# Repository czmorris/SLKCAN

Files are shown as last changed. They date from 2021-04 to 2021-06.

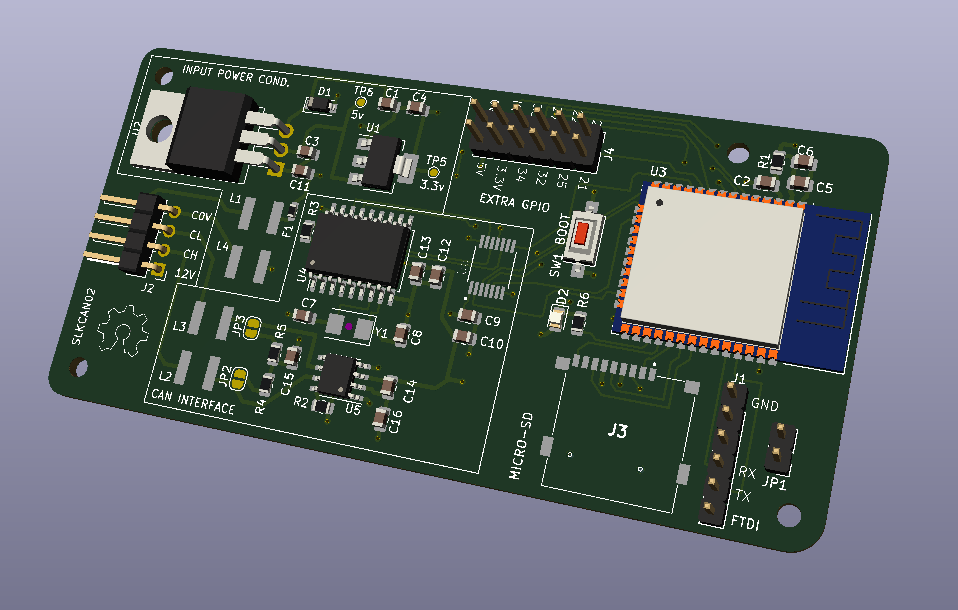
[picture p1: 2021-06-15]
SLKCAN/Renders/Front.PNG

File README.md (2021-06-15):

# SLKCAN
SLKCAN (Slick CAN) PCB. 

This board was created as project to connect to the CANBus on a City Slicker electric motorcycle (Though it may work with other canbus devices).

Goal:
- Programmable via the Arduino IDE (Uses an ESP32). This allows anyone who uses it to customize it to their own needs.
- Connect to the CANBus on the motorcycle. (Uses MCP2551 and MCP2515, Noise management was also required)
- Provide a means to get 3.3 and 5v power from the 12v supply on the bikes data port.
- Provide a means to get this information out via serial. Or to be reprogrammed via serial. Pin header provided.
- Provide a header with some additional GPIO.

note: I use an FTDI cable for programming and getting serial terminal information.
I have also tested with cheaper USB TTL modules with no issues. Other adapters may work as well.

At this time this device does not promise to be foolproof. Connect this to your bike at your own risk.

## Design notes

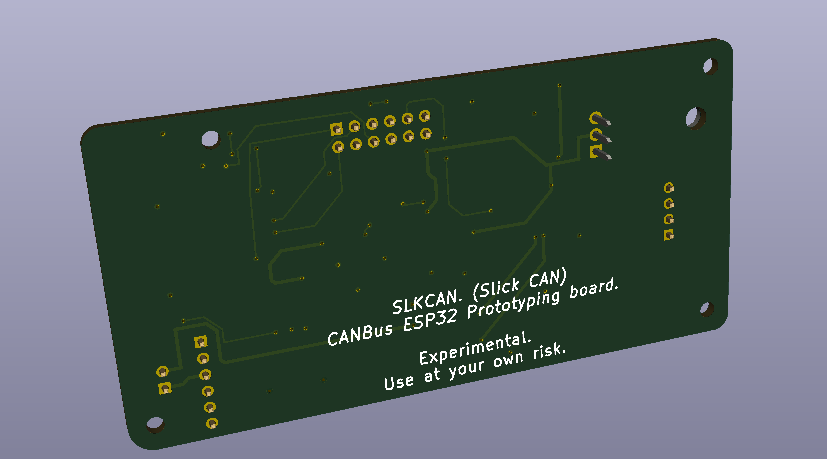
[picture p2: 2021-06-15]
SLKCAN/Renders/Back.PNG

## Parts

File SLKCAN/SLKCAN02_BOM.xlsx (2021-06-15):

Comment | Designator | Footprint | LCSC Part #（optional）
15uH Ind | L1, L2, L3, L4 | SWPA5020 | C55435 (https://lcsc.com/product-detail/Power-Inductors_Sunlord-SWPA5020S150MT_C55435.html/?href=jlc-SMT)
Fuse | F1 | 603 | C207010 (https://lcsc.com/product-detail/PTC-Resettable-Fuses_Littelfuse-0603L010YR_C207010.html/?href=jlc-SMT)
5vREG | U2 | TO-220 | C283283 (https://lcsc.com/product-detail/Dropout-Regulators-LDO_STMicroelectronics-LD1085V50_C283283.html/?href=jlc-SMT)
3.3REG | U1 | SOT-223 | C6186 (https://lcsc.com/product-detail/Low-Dropout-Regulators-LDO_AMS_AMS1117-3-3_AMS1117-3-3_C6186.html/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)
ESP | U3 | QFN-38 | C82899 (https://lcsc.com/product-detail/WIFI-Modules_Espressif-Systems-ESP32-WROOM-32_C82899.html/?href=jlc-SMT)
SD | J3 | 14.5x14.75X1.85mm | C111196 (https://lcsc.com/product-detail/Card-Sockets-Connectors_SOFNG-TF-15x15_C111196.html/?href=jlc-SMT)
LVL IC | U6 | TSSOP-14 | C44955 (https://lcsc.com/product-detail/Level-Translators-Shifters_Texas-Instruments-TXS0104EPWR_C44955.html)
MCP | U4 | SOIC-18 | C12368 (https://lcsc.com/product-detail/CAN_MICROCHIP_MCP2515-I-SO_MCP2515-I-SO_C12368.html/?href=jlc-SMT)
MCP | U5 | SOIC-8 | C49558 (https://lcsc.com/product-detail/MICROCHIP_MICROCHIP_MCP2551T-I-SN_MCP2551T-I-SN_C49558.html/?href=jlc-SMT)
XTAL | Y1 | SMD-5032 | C115962 (https://lcsc.com/product-detail/SMD-Crystal-Resonators_Yangxing-Tech-X50328MSB2GI_C115962.html/?href=jlc-SMT)
DIODE | D1 | SOD-123 | C727113 (https://lcsc.com/product-detail/Schottky-Barrier-Diodes-SBD_TWGMC-1N5817W_C727113.html/?href=jlc-SMT)
LED | D2 | LED_0805 | C84256 (https://lcsc.com/product-detail/Light-Emitting-Diodes-LED_Red-LED-SMDLED-80-180mcd_C84256.html/?href=jlc-SMT)
.1uF | C6, C9-13, C16 | 805 | C696367 (https://lcsc.com/product-detail/Multilayer-Ceramic-Capacitors-MLCC-SMD-SMT_KEMET-C0805C104K1RECAUTO_C696367.html/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)
10uF | C1, C3-5 | 805 | C15850 (https://lcsc.com/product-detail/Multilayer-Ceramic-Capacitors-MLCC-SMD-SMT_SAMSUNG_CL21A106KAYNNNE_10uF-106-10-25V_C15850.html/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)
1uF | C2 | 805 | C28323 (https://lcsc.com/product-detail/Multilayer-Ceramic-Capacitors-MLCC-SMD-SMT_SAMSUNG_CL21B105KBFNNNE_1uF-105-10-50V_C28323.html/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)
22pF | C7, C8 | 805 | C1804 (https://lcsc.com/product-detail/Multilayer-Ceramic-Capacitors-MLCC-SMD-SMT_SAMSUNG_CL21C220JBANNNC_22pF-220-5-50V_C1804.html/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)
150pF | C14, C15 | 805 | C1716 (https://lcsc.com/product-detail/Multilayer-Ceramic-Capacitors-MLCC-SMD-SMT_150pF-151-10-50V_C1716.html/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)
10K | R1-3 | 805 | C17414 (https://lcsc.com/product-detail/Chip-Resistor-Surface-Mount_Uniroyal-Elec-0805W8F1002T5E_C17414.html/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)
1K | R6 | 805 | C17513
60 | R4-5 | 805 | C72998 (https://lcsc.com/product-detail/Chip-Resistor-Surface-Mount_Uniroyal-Elec-0805W8F604JT5E_C72998.html/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)
BTN | SW1 | SW-SMD-3.6X6.1 | C118141 (https://lcsc.com/product-detail/Tactile-Switches_Korean-Hroparts-Elec-K2-1107ST-A4SW-06_C118141.html/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)

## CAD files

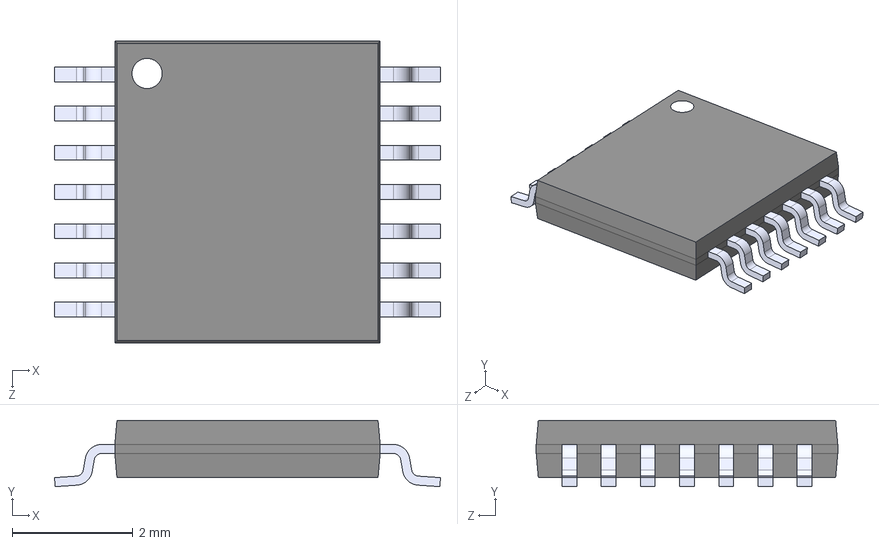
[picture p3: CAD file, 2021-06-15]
SLKCAN/downloads/74LVC125APW_118/74LVC125APW_118.step
6.40 x 1.10 x 5.00 mm

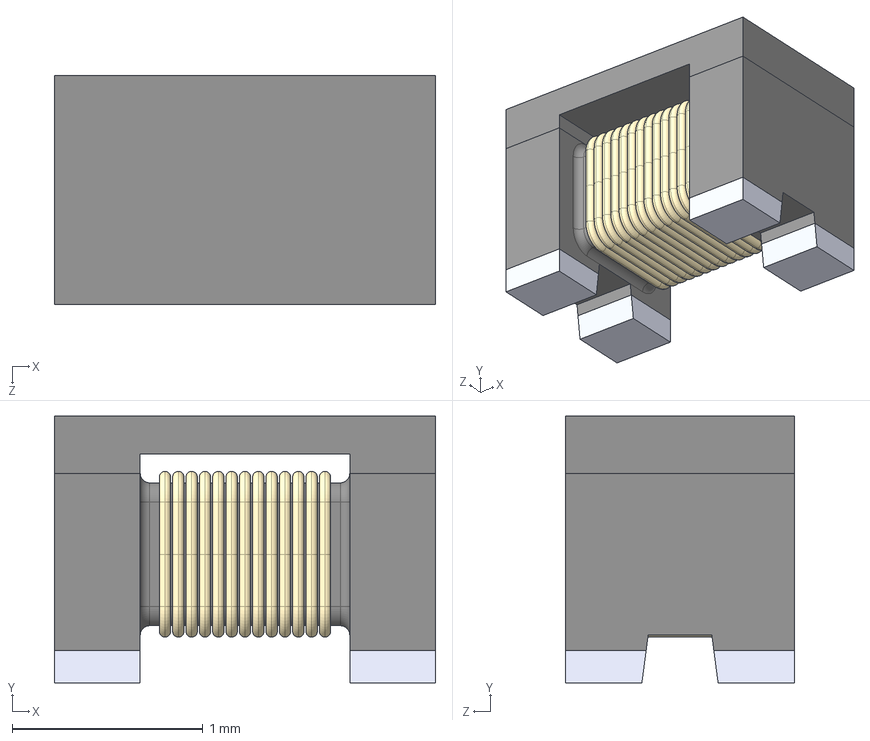
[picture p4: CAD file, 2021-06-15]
SLKCAN/downloads/DLW21SN121SQ2L/DLW21SN121SQ2L.step
2.00 x 1.40 x 1.20 mm

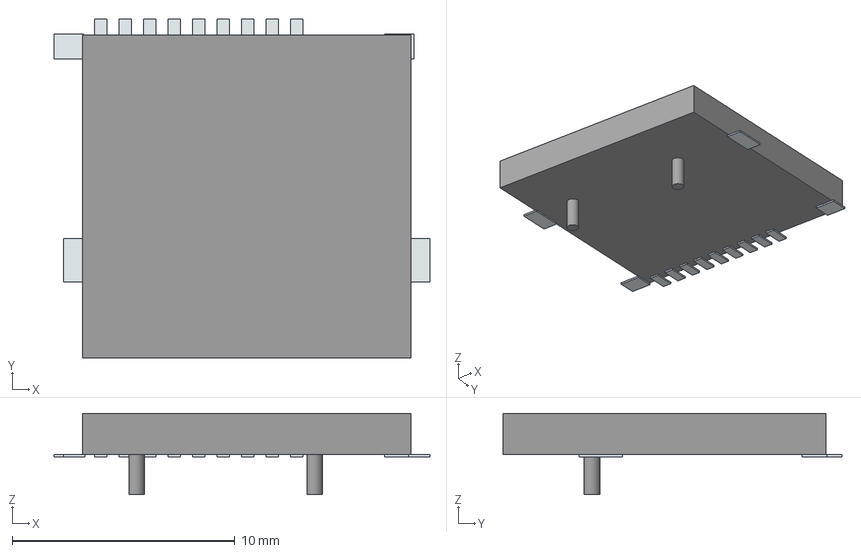
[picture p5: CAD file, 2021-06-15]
SLKCAN/downloads/LIB_TF-15X15/TF-15X15/3D/TF-15X15.stp
16.9 x 15.2 x 3.65 mm
Pins
Lugs x 2

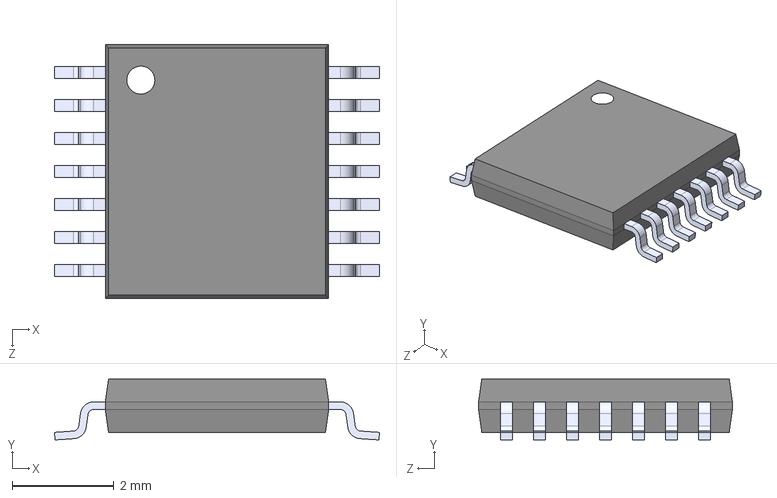
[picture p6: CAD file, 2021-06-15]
SLKCAN/downloads/LSF0204PWR/LSF0204PWR.step
6.40 x 1.20 x 5.00 mm

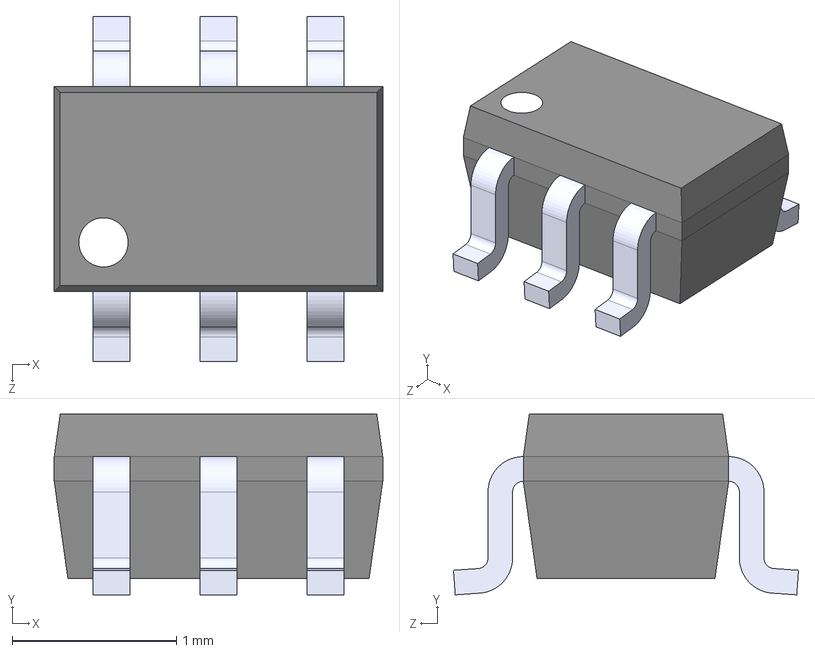
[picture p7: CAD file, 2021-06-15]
SLKCAN/downloads/SN74AVC1T45DCKR/SN74AVC1T45DCKR.step
2.00 x 1.10 x 2.10 mm

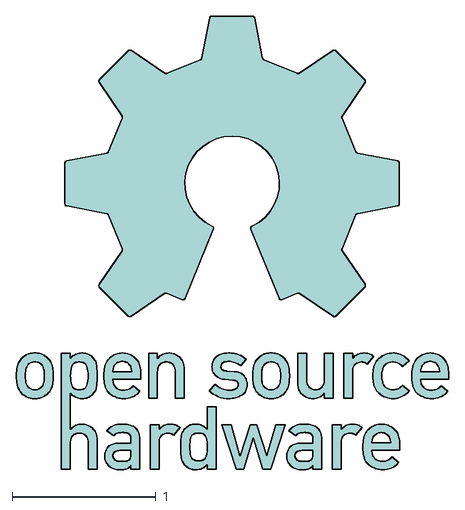
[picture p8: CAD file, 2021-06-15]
SLKCAN/downloads/OSHW-Logo-R2000.dxf
3.00 x 3.15

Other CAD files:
SLKCAN/downloads/LIB_TF-15X15/TF-15X15/3D/TF-15X15.stl
SLKCAN/downloads/LIB_TF-15X15/TF-15X15/Allegro/tf15x15.psm
SLKCAN/downloads/LIB_TF-15X15/TF-15X15/DEHDL/tf_15x15/chips/chips.prt

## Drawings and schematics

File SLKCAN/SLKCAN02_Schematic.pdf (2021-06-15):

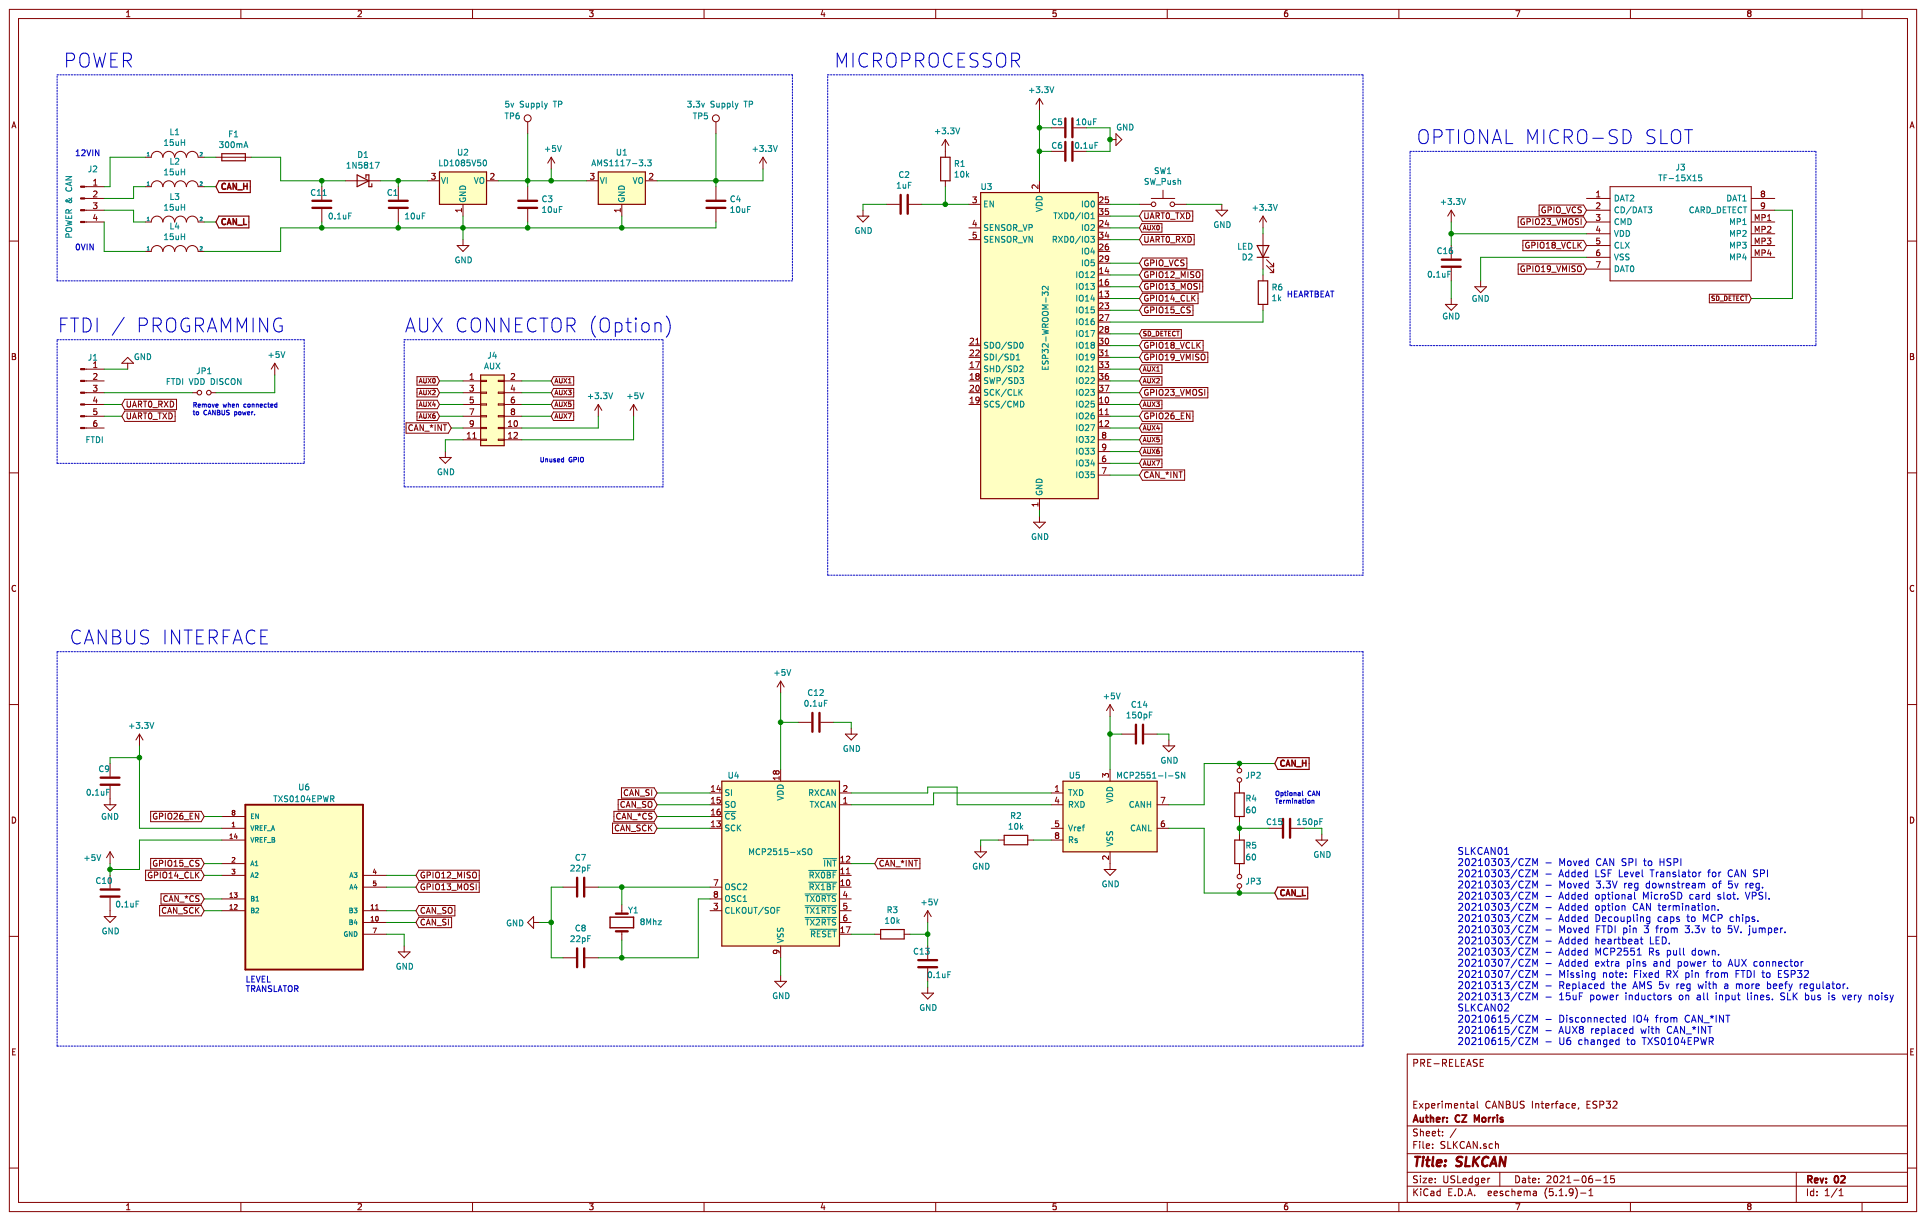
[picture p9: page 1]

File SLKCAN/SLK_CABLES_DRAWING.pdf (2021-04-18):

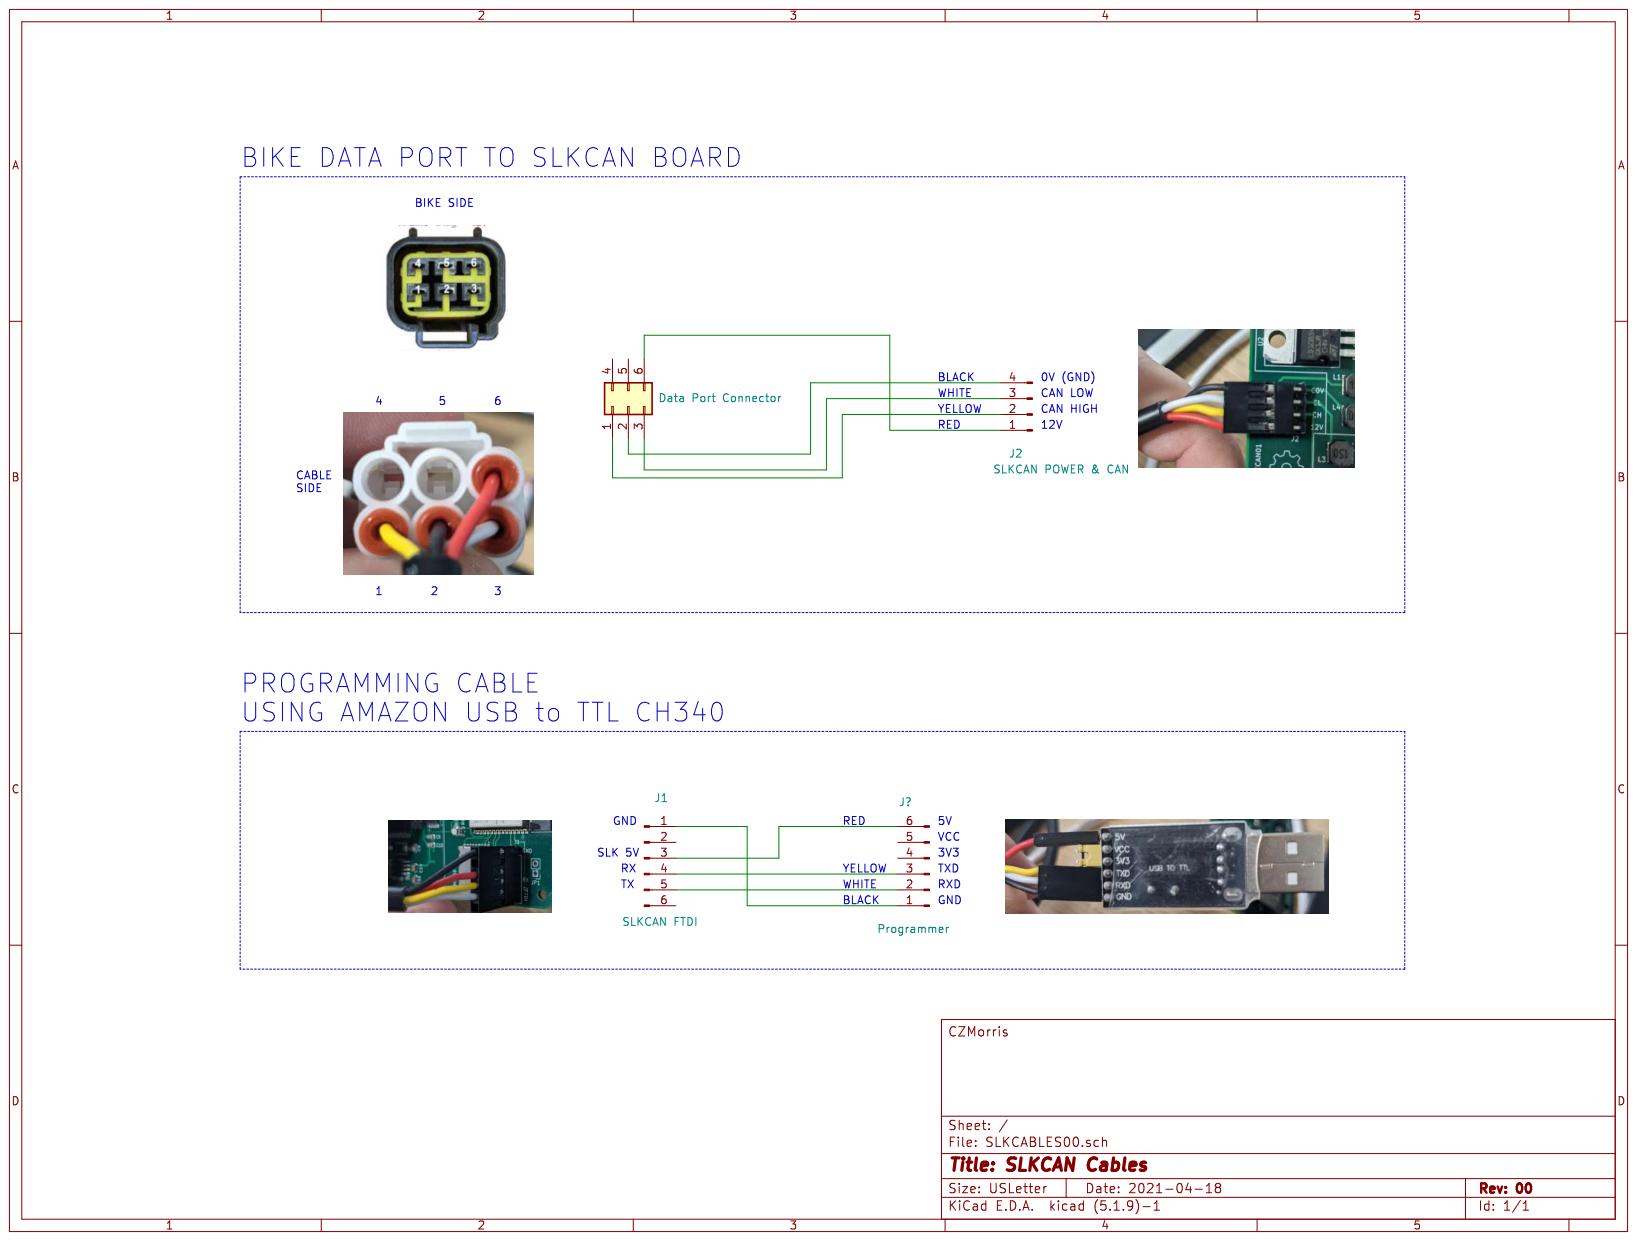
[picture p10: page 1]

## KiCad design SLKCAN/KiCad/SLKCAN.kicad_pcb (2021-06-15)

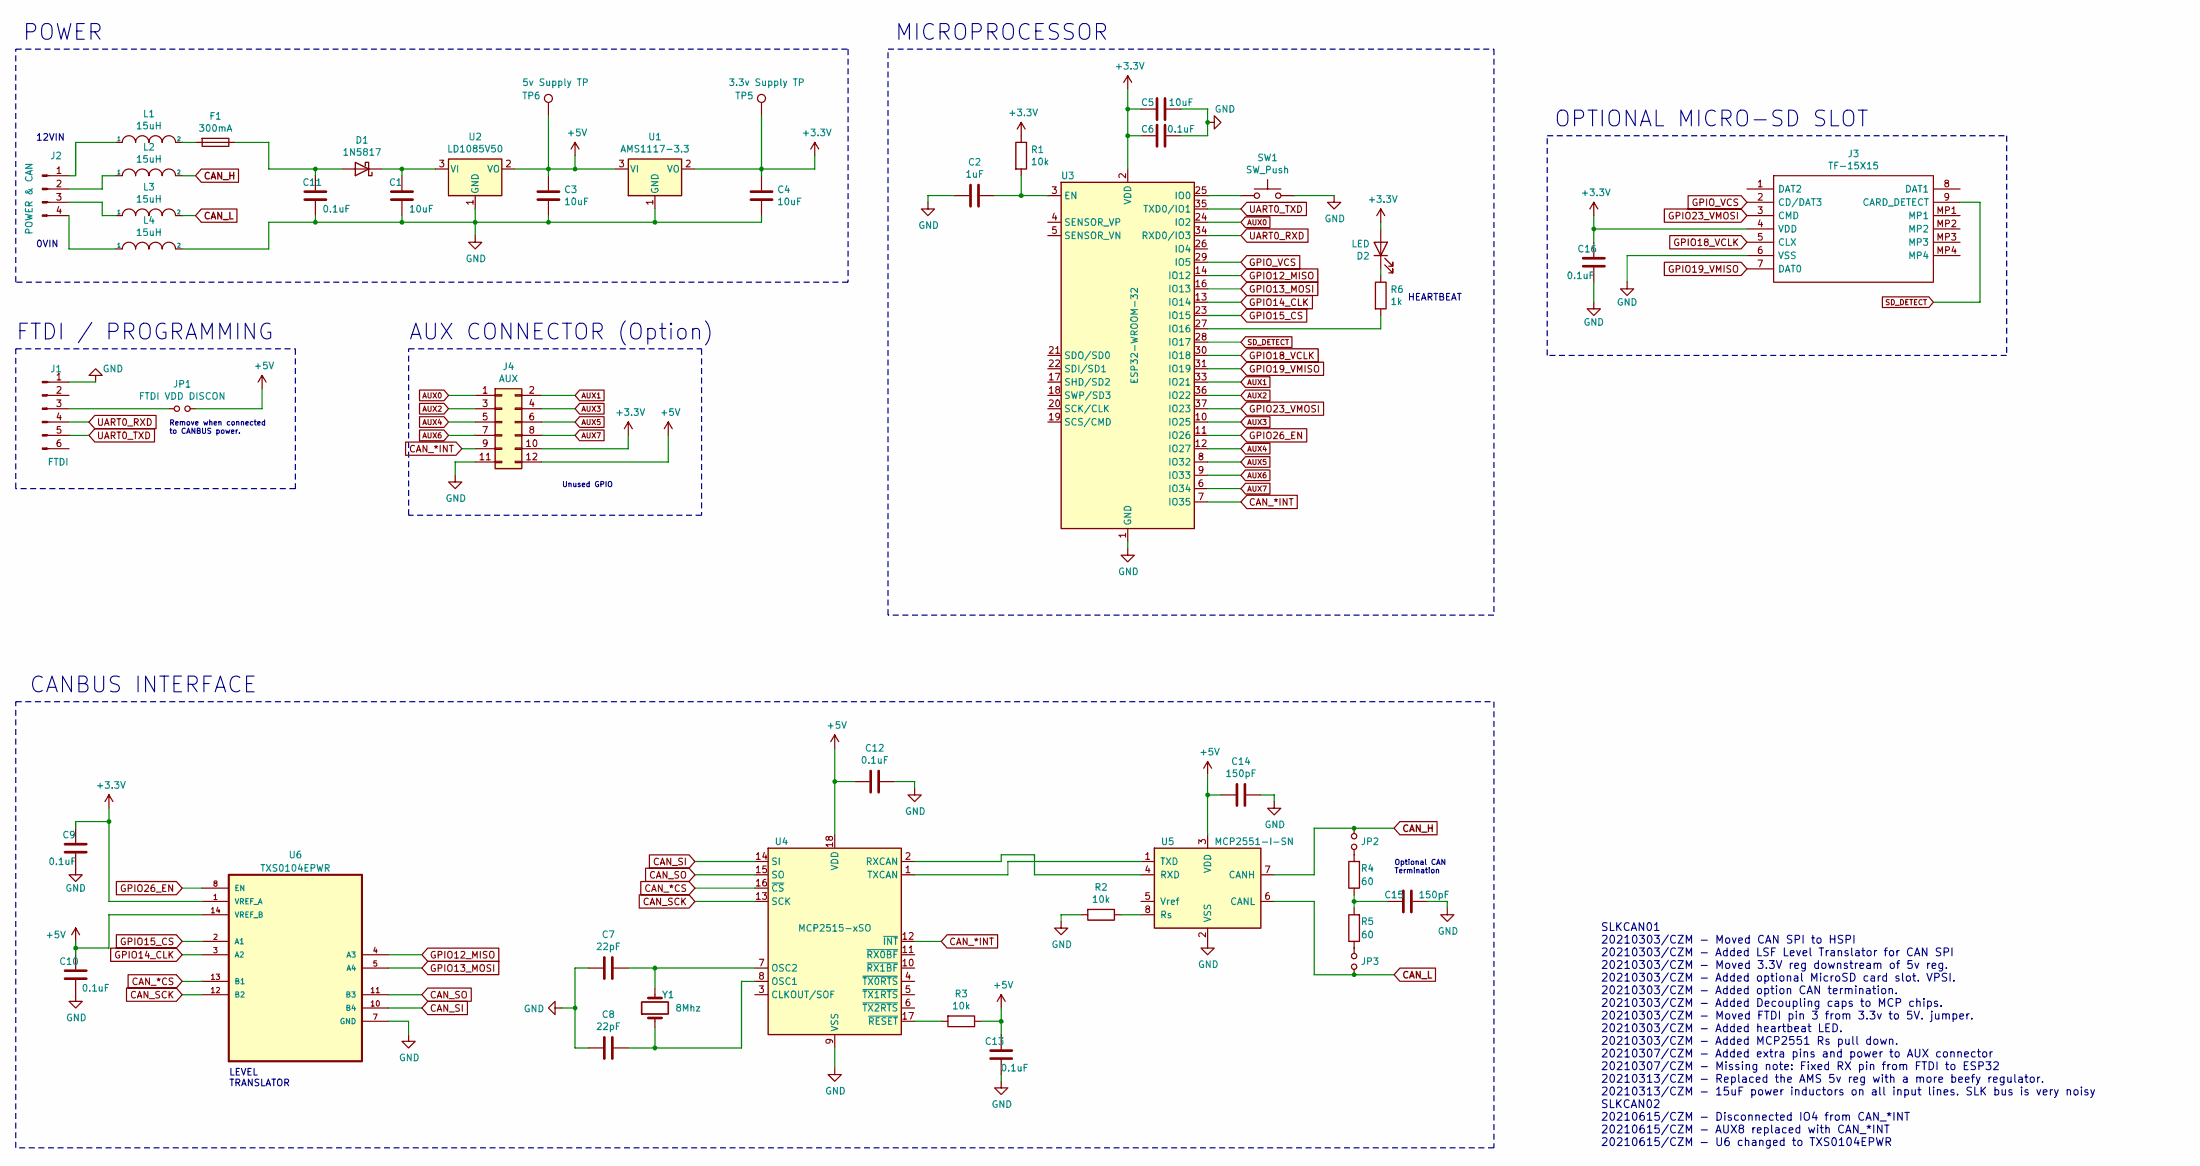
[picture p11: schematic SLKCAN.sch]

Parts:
C1, C3, C4, C5: 10uF; C_0805_2012Metric
C2: 1uF; C_0805_2012Metric
C6, C9, C10, C11, C12, C13, C16: 0.1uF; C_0805_2012Metric
C7, C8: 22pF; C_0805_2012Metric
C14, C15: 150pF; C_0805_2012Metric
D1: 1N5817; D_SOD-123
D2: LED; LED_0805_2012Metric
F1: 300mA; Fuse_0603_1608Metric
J1: FTDI; PinHeader_1x06_P2.54mm_Vertical
J2: POWER & CAN; PinHeader_1x04_P2.54mm_Horizontal
J3: TF-15X15; TF15X15; Manufacturer_Part_Number TF-15X15
J4: AUX; PinHeader_2x06_P2.54mm_Vertical
JP1: FTDI VDD DISCON; PinHeader_1x02_P2.54mm_Vertical
JP2, JP3: Jumper_NO_Small; SolderJumper-2_P1.3mm_Open_RoundedPad1.0x1.5mm
L1, L2, L3, L4: 15uH; SUNLORD_SWPA5020S_CZM
R1, R2, R3: 10k; R_0805_2012Metric
R4, R5: 60; R_0805_2012Metric
R6: 1k; R_0805_2012Metric
SW1: SW_Push; SW_SPST_CK_RS282G05A3
TP5: 3.3v Supply TP; TestPoint_Pad_D1.0mm
TP6: 5v Supply TP; TestPoint_Pad_D1.0mm
U1: AMS1117-3.3; SOT-223-3_TabPin2
U2: LD1085V50; TO-220-3_Horizontal_TabDown
U3: ESP32-WROOM-32
U4: MCP2515-xSO; SOIC-18W_7.5x11.6mm_P1.27mm
U5: MCP2551-I-SN; SOIC-8_3.9x4.9mm_P1.27mm
U6: TXS0104EPWR; SOP65P640X120-14N
Y1: 8Mhz; Crystal_SMD_5032-2Pin_5.0x3.2mm

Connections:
+3V3: C4.1, C5.2, C6.2, C9.2, C16.2, D2.2 (A), J3.4 (VDD), J4.10, R1.1, TP5.1, U1.2 (VO), U3.2 (VDD), U6.1 (VREF_A)
+5V: C3.1, C10.2, C12.2, C13.2, C14.2, J4.12, JP1.2, R3.1, TP6.1, U1.3 (VI), U2.2 (VO), U4.18 (VDD), U5.3 (VDD), U6.14 (VREF_B)
AUX0: J4.1, U3.24 (IO2)
AUX1: J4.2, U3.33 (IO21)
AUX2: J4.3, U3.36 (IO22)
AUX3: J4.4, U3.10 (IO25)
AUX4: J4.5, U3.12 (IO27)
AUX5: J4.6, U3.8 (IO32)
AUX6: J4.7, U3.9 (IO33)
AUX7: J4.8, U3.6 (IO34)
CAN_*CS: U4.16 (~CS), U6.13 (B1)
CAN_*INT: J4.9, U3.7 (IO35), U4.12 (~INT)
CAN_H: JP2.1, L2.2, U5.7 (CANH)
CAN_L: JP3.2, L3.2, U5.6 (CANL)
CAN_SCK: U4.13 (SCK), U6.12 (B2)
CAN_SI: U4.14 (SI), U6.10 (B4)
CAN_SO: U4.15 (SO), U6.11 (B3)
GND: C1.2, C2.2, C3.2, C4.2, C5.1, C6.1, C7.2, C8.2, C9.1, C10.1, C11.2, C12.1, C13.1, C14.1, C15.2, C16.1, J1.1, J3.6 (VSS), J4.11, L4.2, R2.2, SW1.2, U1.1 (GND), U2.1 (GND), U3.1 (GND), U3.15 (GND), U3.38 (GND), U3.39 (GND), U4.9 (VSS), U5.2 (VSS), U6.7 (GND)
GPIO12_MISO: U3.14 (IO12), U6.4 (A3)
GPIO13_MOSI: U3.16 (IO13), U6.5 (A4)
GPIO14_CLK: U3.13 (IO14), U6.3 (A2)
GPIO15_CS: U3.23 (IO15), U6.2 (A1)
GPIO18_VCLK: J3.5 (CLX), U3.30 (IO18)
GPIO19_VMISO: J3.7 (DAT0), U3.31 (IO19)
GPIO23_VMOSI: J3.3 (CMD), U3.37 (IO23)
GPIO26_EN: U3.11 (IO26), U6.8 (EN)
GPIO_VCS: J3.2 (CD/DAT3), U3.29 (IO5)
unnamed: C1.1, D1.1 (K), U2.3 (VI)
unnamed: C2.1, R1.2, U3.3 (EN)
unnamed: C7.1, U4.7 (OSC2), Y1.2
unnamed: C8.1, U4.8 (OSC1), Y1.1
unnamed: C11.1, D1.2 (A), F1.1
unnamed: C15.1, R4.1, R5.2
unnamed: D2.1 (K), R6.1
unnamed: F1.2, L1.2
unnamed: J1.3, JP1.1
unnamed: J2.1, L1.1
unnamed: J2.2, L2.1
unnamed: J2.3, L3.1
unnamed: J2.4, L4.1
unnamed: JP2.2, R4.2
unnamed: JP3.1, R5.1
unnamed: R2.1, U5.8 (Rs)
unnamed: R3.2, U4.17 (~RESET)
unnamed: R6.2, U3.27 (IO16)
unnamed: SW1.1, U3.25 (IO0)
unnamed: U4.1 (TXCAN), U5.1 (TXD)
unnamed: U4.2 (RXCAN), U5.4 (RXD)
SD_DETECT: J3.9 (CARD_DETECT), U3.28 (IO17)
UART0_RXD: J1.4, U3.34 (RXD0/IO3)
UART0_TXD: J1.5, U3.35 (TXD0/IO1)

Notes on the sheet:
LEVEL TRANSLATOR
12VIN
0VIN
HEARTBEAT
POWER
FTDI / PROGRAMMING
MICROPROCESSOR
OPTIONAL MICRO-SD SLOT
CANBUS INTERFACE
SLKCAN01 20210303/CZM - Moved CAN SPI to HSPI 20210303/CZM - Added LSF Level Translator for CAN SPI 20210303/CZM - Moved 3.3V reg downstream of 5v reg. 20210303/CZM - Added optional MicroSD card slot. VPSI. 20210303/CZM - Added option CAN termination. 20210303/CZM - Added Decoupling caps to MCP chi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
Optional CAN Termination
AUX CONNECTOR (Option)
Remove when connected to CANBUS power.
Unused GPIO

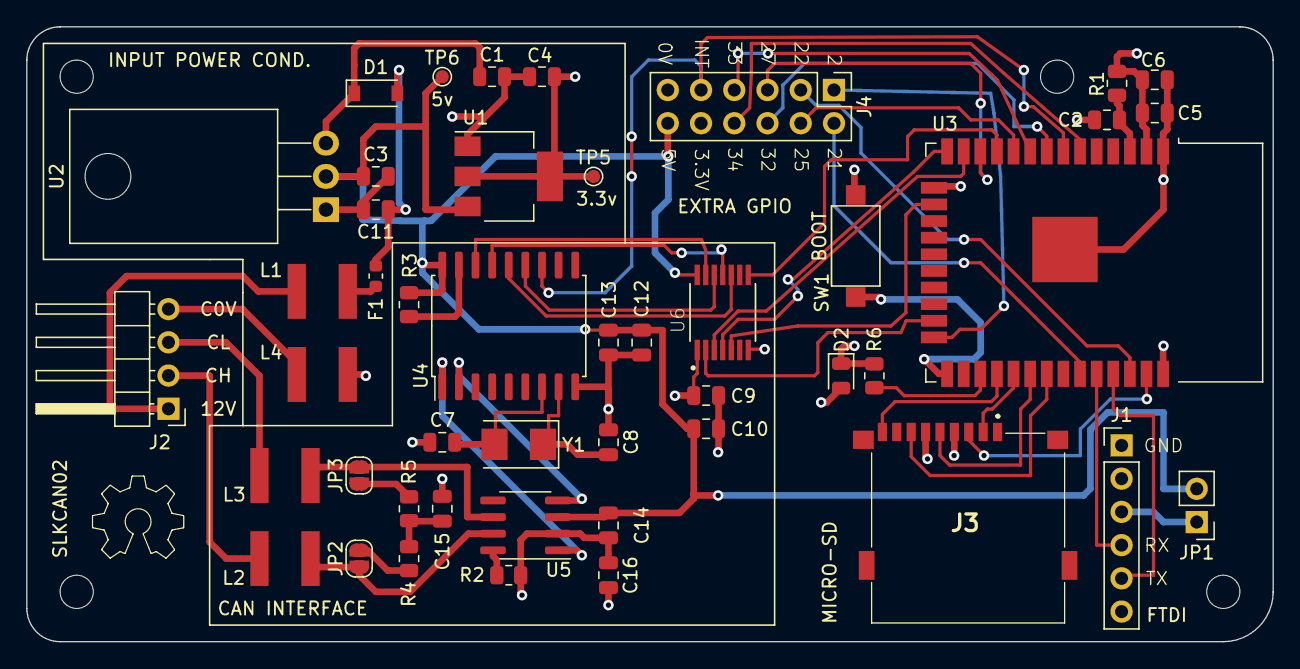
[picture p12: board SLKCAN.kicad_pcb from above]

Board: 4 copper layers, 95.3 x 47.0 mm, 46 parts (0 on the bottom side), 51 nets.

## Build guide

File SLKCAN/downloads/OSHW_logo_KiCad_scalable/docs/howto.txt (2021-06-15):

How to make your own:
---------------------

Watch / read this first:

* http://www.kicad-pcb.org/display/KICAD/Videos+by+zupnikal

The last two videos should be helpful for how to create a custom .emp file from images.

* http://www.re-innovation.co.uk/web12/index.php/en/blog-75/230-adding-logo-to-kicad

If you use linux (which you should), you don't have to use the online-scaler. Just use the scripts!

---

* Create a folder to hold your new footprint library.
* Copy the scripts 'make_lib.sh' and 'scale.pl' into that folder.
* Make sure these files are executable (chmod u+x ...).
* Copy your custom .emp file into that foler.

* Run the 'make_lib.sh' script as follows:

./make_lib.sh input-file.emp lib-name.mod START END

START and END are placeholders for positive integer numbers (1,2,3...) that determine
the range of created footprint sizes. The units are metric (mm).

The 'lib-name.mod' file will show up in the 'lib' sub-folder. Add it to your pcbnew
library settings as usual.

Footprints that are created for back-layers are automagically mirrored horizontally.
To place them onto a back-layer, hover the mouse-pointer over them and press 'f' for 'flip'.

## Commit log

2021-04-14 Added Rework notes schematic
    Added rework notes in RED to the schematic pdf file. Rework notes represent the changes that needed to be made to the board after production.
2021-04-18 Added cables drawing
2021-06-15 Fixes from SLKCAN01 known issues
    Fixes from SLKCAN01 known issues.
    [74LVC125APW_118.step, DLW21SN121SQ2L.step, EDI2CAP.CFG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]
2021-06-15 Removed old gerbers, pdfs, and renders
    Removed old gerbers, pdfs, and renders
    [SLKCAN-B_Cu.gbr, SLKCAN-B_Mask.gbr, SLKCAN-B_Paste.gbr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]
2021-06-15 New gerbers, rendres, and schematic pdf.
    New gerbers, rendres, and schematic pdf.
    Note: At this time I have not ordered and tested this revision. If you decide to order some use caution.
    [SLKCAN-B_Cu.gbr, SLKCAN-B_Mask.gbr, SLKCAN-B_Paste.gbr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]
